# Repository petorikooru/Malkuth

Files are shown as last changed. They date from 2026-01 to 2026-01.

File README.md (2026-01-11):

# Malkuth

Idk, the name just comes up in my head (that malkuth from BA)

> [!CAUTION]
> For now, DO NOT USE the PCB Design unless you know what you are doing.
> There are quite silly (and tiny bit major) design flaws on there

> [!NOTE]  
> For now, the audio handling is a bit stuttery on some FLAC audio
> (especially on 24 bit one). I will make it a todo list for now

Basically it is a rewrite version of the previous project of mine [uta](https://github.com/petorikooru/uta)

I create this to fulfill my final project of Microcomputer class lmao.

## Dependencies

- TFT_eSPI + FT6236 + PNGdec
- arduino-audio-tools + libfoxenflac + libmp3helix + libaac + libwav
- SdFat

## Hardware Components

- ILI9488 Capacitive Touch Screen Display
- PCM5102a DAC
- MicroSD Card Module
- ESP32-S3 N16R8
- Kailh Choc v2 switch
- Other small components stuff

For now, 16 MB Storage size is needed to keep the font files (they take like 50% of the spaces 💀). I will make them .vlw files and store it inside SPIFFS or LittleFS (that is the task of future me though)

## Screenshot

<table>
  <tr>
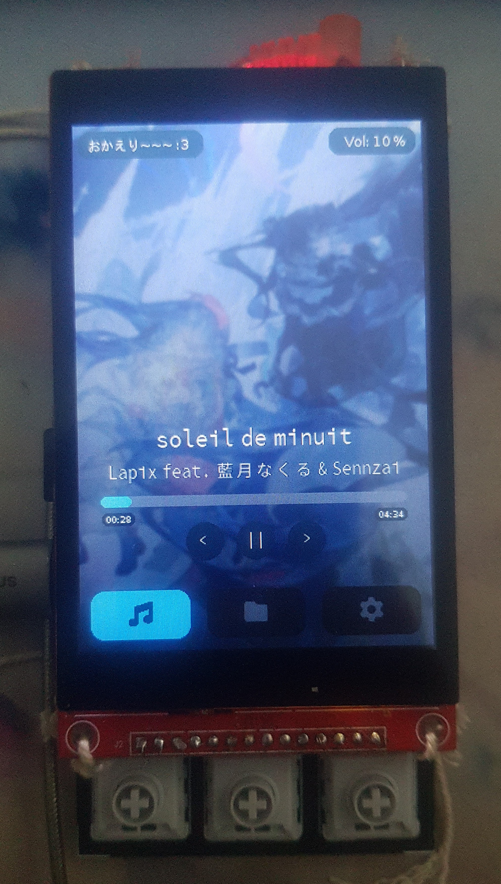
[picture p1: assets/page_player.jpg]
Player Menu
    <td> </td>
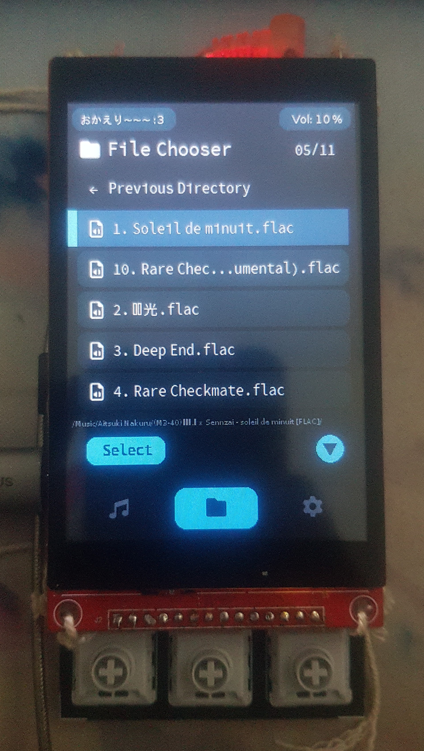
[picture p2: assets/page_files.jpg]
Files Menu
    <td> </td>
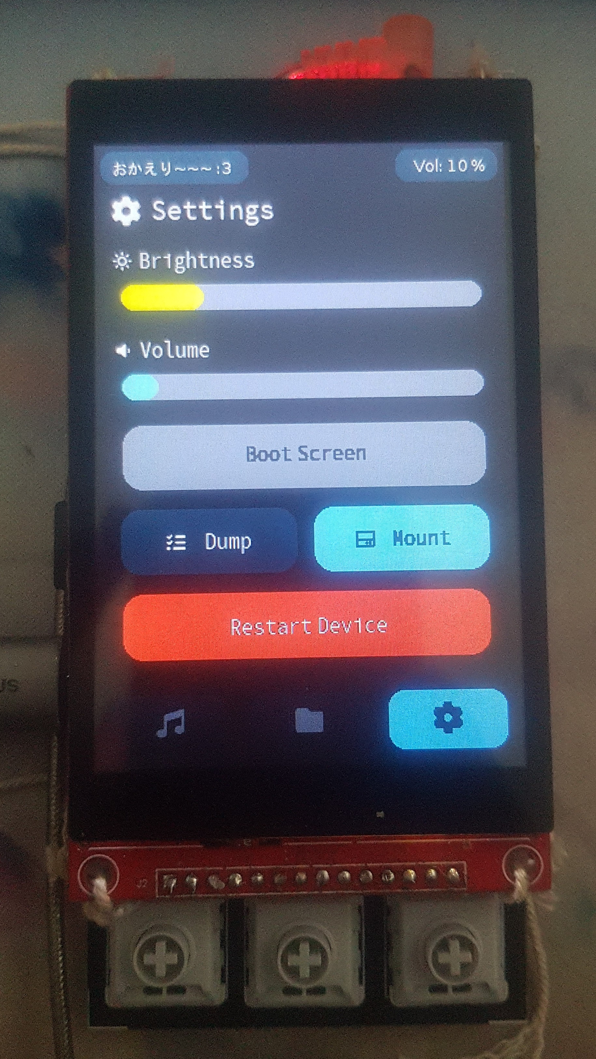
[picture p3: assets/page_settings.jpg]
Settings Menu
    <td> </td>
  </tr> 
</table>

## TODO List

- Make the audio a task itself just like Display (The main trouble is that SdFat is not really thread safe)
- Actually handle audio cover image (jpg and png)
- More performance fixing stuff
- ~Actually handle UI correctly instead of reloading from scratch~ (Kinda done?)
- 3D Printable Case

## Far (not really) to the future TODO LIST

- Maybe split the processing to different chip so that the Display will be driven by RP2040 and the Audio (and perhaps even bluetooth functionality) will be driven by ESP32-S3 (or more powerful counterpart)
- Fix the PCB Design and implement actual charging functionality
- Add speaker (maybe will salvage from iphone speaker or something) and implement automatic audio switching
- RTC clock?
- Animation (i dont think it is powerful enough though)

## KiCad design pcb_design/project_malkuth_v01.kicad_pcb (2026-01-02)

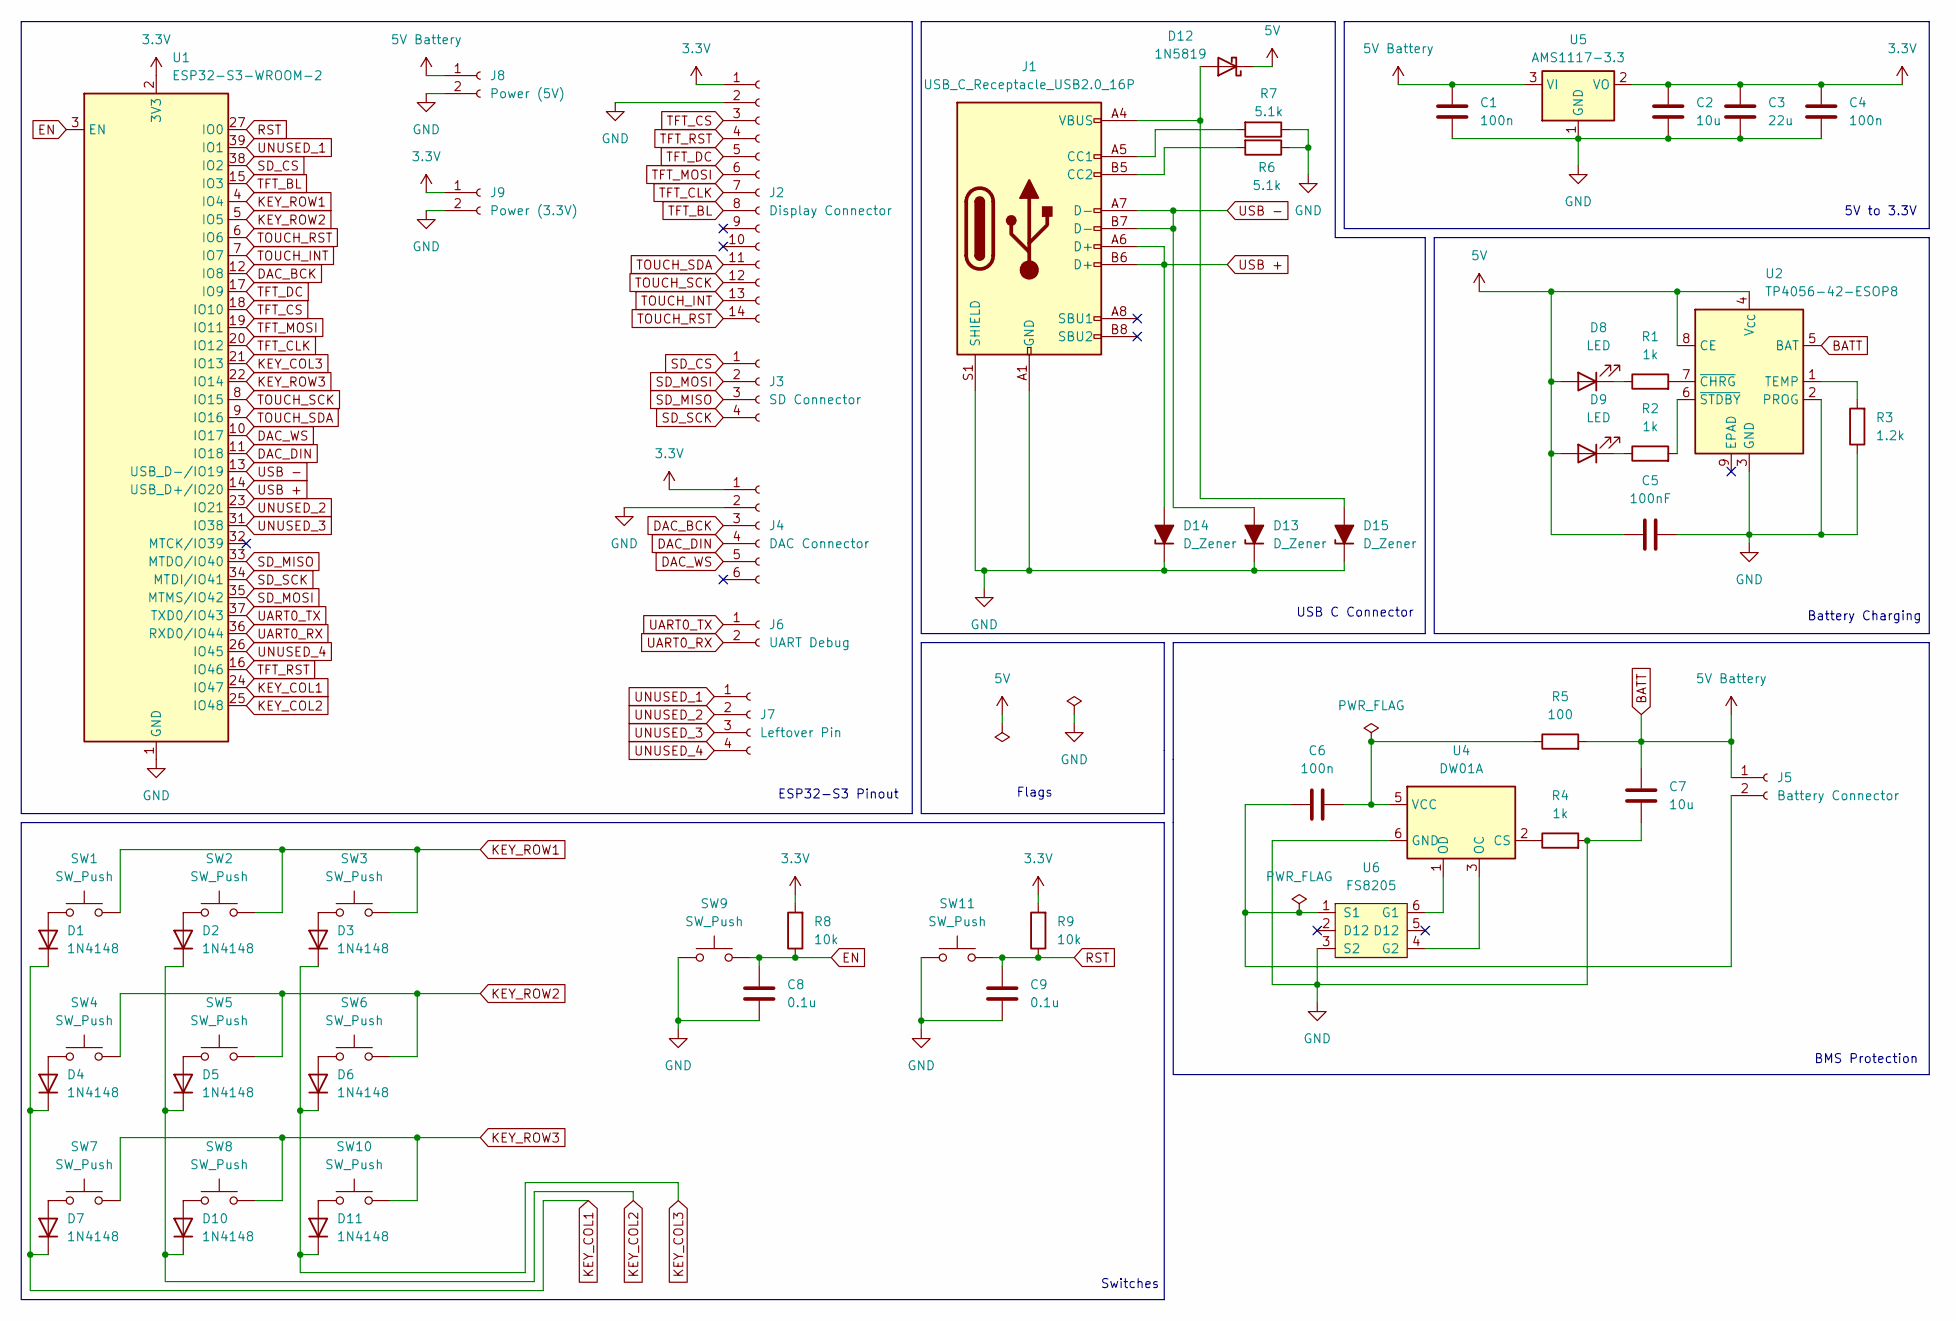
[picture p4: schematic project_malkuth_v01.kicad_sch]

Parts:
C1, C4, C6: 100n; C_0805_2012Metric
C2, C7: 10u; C_0805_2012Metric
C3: 22u; C_0805_2012Metric
C5: 100nF
C8, C9: 0.1u
D1, D2, D3, D4, D5, D6, D7, D10, D11: 1N4148; D_DO-35_SOD27_P7.62mm_Horizontal
D8, D9: LED; LED_0805_2012Metric
D12: 1N5819; D_DO-41_SOD81_P10.16mm_Horizontal
D13, D14, D15: D_Zener; Littelfuse_PolyZen-LS
J1: USB_C_Receptacle_USB2.0_16P; USB_C_Receptacle_GCT_USB4105-xx-A_16P_TopMnt_Horizontal
J2: Display Connector; PinSocket_1x14_P2.00mm_Vertical
J3: SD Connector; PinSocket_1x04_P2.00mm_Vertical
J4: DAC Connector; PinHeader_1x06_P2.00mm_Vertical
J5: Battery Connector; PinSocket_1x02_P2.54mm_Vertical
J6: UART Debug; PinSocket_1x02_P2.00mm_Vertical
J7: Leftover Pin; PinSocket_1x04_P2.00mm_Vertical
J8: Power (5V); PinSocket_1x02_P2.00mm_Vertical
J9: Power (3.3V); PinSocket_1x02_P2.00mm_Vertical
R1, R2, R4: 1k; R_0805_2012Metric
R3: 1.2k; R_0805_2012Metric
R5: 100; R_0805_2012Metric
R6, R7: 5.1k; R_0805_2012Metric
R8, R9: 10k; R_0805_2012Metric
SW1, SW2, SW3: SW_Push; SW_Hotswap_Kailh_Choc_V1V2
SW4, SW5, SW6, SW7, SW8, SW10: SW_Push; SW_Tactile_SPST_Angled_PTS645Vx39-2LFS
SW9, SW11: SW_Push; SW_PUSH_6mm
U1: ESP32-S3-WROOM-2
U2: TP4056-42-ESOP8; SOIC-8-1EP_3.9x4.9mm_P1.27mm_EP2.41x3.3mm_ThermalVias
U4: DW01A; SOT-23-6
U5: AMS1117-3.3; SOT-223-3_TabPin2
U6: FS8205; SOT-23-6; LCSC C32254

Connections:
3.3V: C2.1, C3.1, C4.1, J2.1, J4.1, J9.1, R8.2, R9.2, U1.2 (3V3), U5.2 (VO)
5V: C5.2, D8.2 (A), D9.2 (A), D12.1 (K), U2.4 (V_{CC}), U2.8 (CE)
BATT: C1.1, C7.1, J5.1, J8.1, R5.2, U2.5 (BAT), U5.3 (VI)
DAC_BCK: J4.3, U1.12 (IO8)
DAC_DIN: J4.4, U1.11 (IO18)
DAC_WS: J4.5, U1.10 (IO17)
EN: C8.1, R8.1, SW9.2, U1.3 (EN)
GND: C1.2, C2.2, C3.2, C4.2, C5.1, C7.2, C8.2, C9.2, D13.1 (K), D14.1 (K), D15.1 (K), J1.A1 (GND), J1.A12 (GND), J1.B1 (GND), J1.B12 (GND), J1.S1 (SHIELD), J2.2, J4.2, J8.2, J9.2, R3.1, R4.2, R6.1, R7.1, SW9.1, SW11.1, U1.1 (GND), U1.40 (GND), U1.41 (GND), U2.2 (PROG), U2.3 (GND), U4.6 (GND), U5.1 (GND), U6.3 (S2)
KEY_COL1: D1.1 (K), D4.1 (K), D7.1 (K), U1.24 (IO47)
KEY_COL2: D2.1 (K), D5.1 (K), D10.1 (K), U1.25 (IO48)
KEY_COL3: D3.1 (K), D6.1 (K), D11.1 (K), U1.21 (IO13)
KEY_ROW1: SW1.2, SW2.2, SW3.2, U1.4 (IO4)
KEY_ROW2: SW4.2, SW5.2, SW6.2, U1.5 (IO5)
KEY_ROW3: SW7.2, SW8.2, SW10.2, U1.22 (IO14)
unnamed: D1.2 (A), SW1.1
unnamed: D2.2 (A), SW2.1
unnamed: D3.2 (A), SW3.1
unnamed: D4.2 (A), SW4.1
unnamed: D5.2 (A), SW5.1
unnamed: D6.2 (A), SW6.1
unnamed: D7.2 (A), SW7.1
unnamed: D8.1 (K), R1.1
unnamed: D9.1 (K), R2.1
unnamed: D10.2 (A), SW8.1
unnamed: D11.2 (A), SW10.1
unnamed: D12.2 (A), D15.2 (A), J1.A4 (VBUS), J1.A9 (VBUS), J1.B4 (VBUS), J1.B9 (VBUS)
unnamed: J1.A5 (CC1), R7.2
unnamed: J1.B5 (CC2), R6.2
unnamed: C6.1, J5.2, U6.1 (S1)
unnamed: R3.2, U2.1 (TEMP)
unnamed: R1.2, U2.7 (~CHRG)
unnamed: R2.2, U2.6 (~STDBY)
unnamed: R4.1, U4.2 (CS)
unnamed: U4.3 (OC), U6.4 (G2)
unnamed: U4.1 (OD), U6.6 (G1)
unnamed: C6.2, R5.1, U4.5 (VCC)
RST: C9.1, R9.1, SW11.2, U1.27 (IO0)
SD_CS: J3.1, U1.38 (IO2)
SD_MISO: J3.3, U1.33 (MTDO/IO40)
SD_MOSI: J3.2, U1.35 (MTMS/IO42)
SD_SCK: J3.4, U1.34 (MTDI/IO41)
TFT_BL: J2.8, U1.15 (IO3)
TFT_CLK: J2.7, U1.20 (IO12)
TFT_CS: J2.3, U1.18 (IO10)
TFT_DC: J2.5, U1.17 (IO9)
TFT_MOSI: J2.6, U1.19 (IO11)
TFT_RST: J2.4, U1.16 (IO46)
TOUCH_INT: J2.13, U1.7 (IO7)
TOUCH_RST: J2.14, U1.6 (IO6)
TOUCH_SCK: J2.12, U1.8 (IO15)
TOUCH_SDA: J2.11, U1.9 (IO16)
UART0_RX: J6.2, U1.36 (RXD0/IO44)
UART0_TX: J6.1, U1.37 (TXD0/IO43)
UNUSED_1: J7.1, U1.39 (IO1)
UNUSED_2: J7.2, U1.23 (IO21)
UNUSED_3: J7.3, U1.31 (IO38)
UNUSED_4: J7.4, U1.26 (IO45)
USB +: D14.2 (A), J1.A6 (D+), J1.B6 (D+), U1.14 (USB_D+/IO20)
USB -: D13.2 (A), J1.A7 (D-), J1.B7 (D-), U1.13 (USB_D-/IO19)

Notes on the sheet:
5V to 3.3V
Flags
BMS Protection
Switches
ESP32-S3 Pinout
Battery Charging
USB C Connector

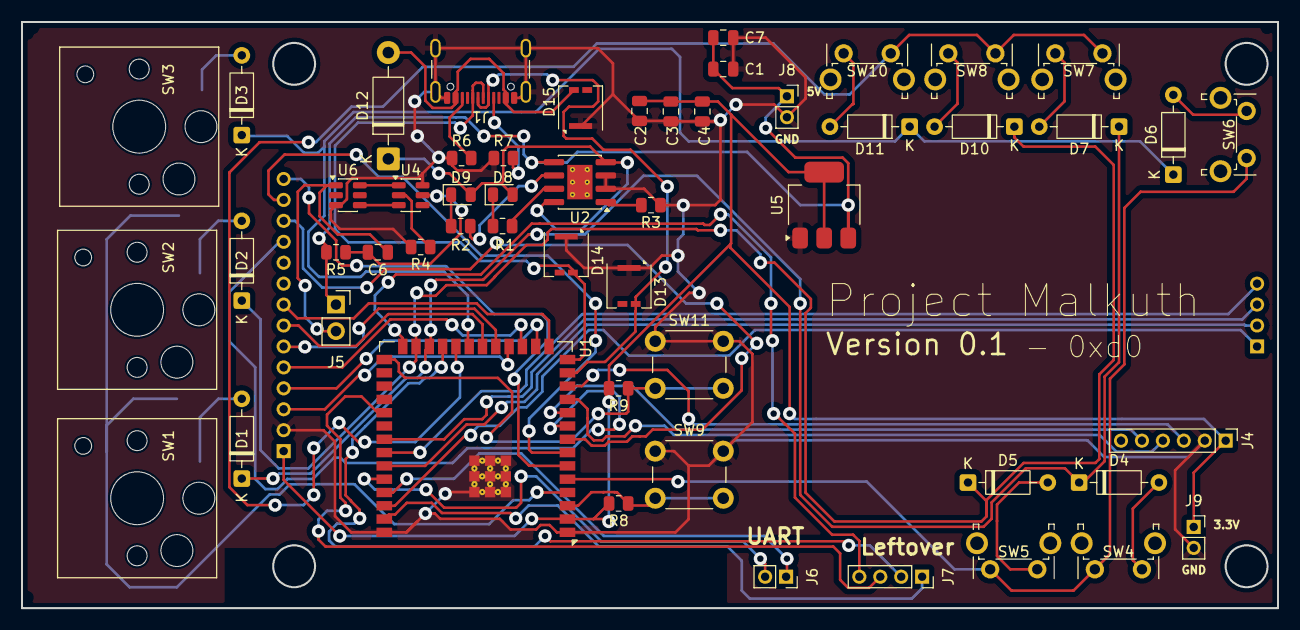
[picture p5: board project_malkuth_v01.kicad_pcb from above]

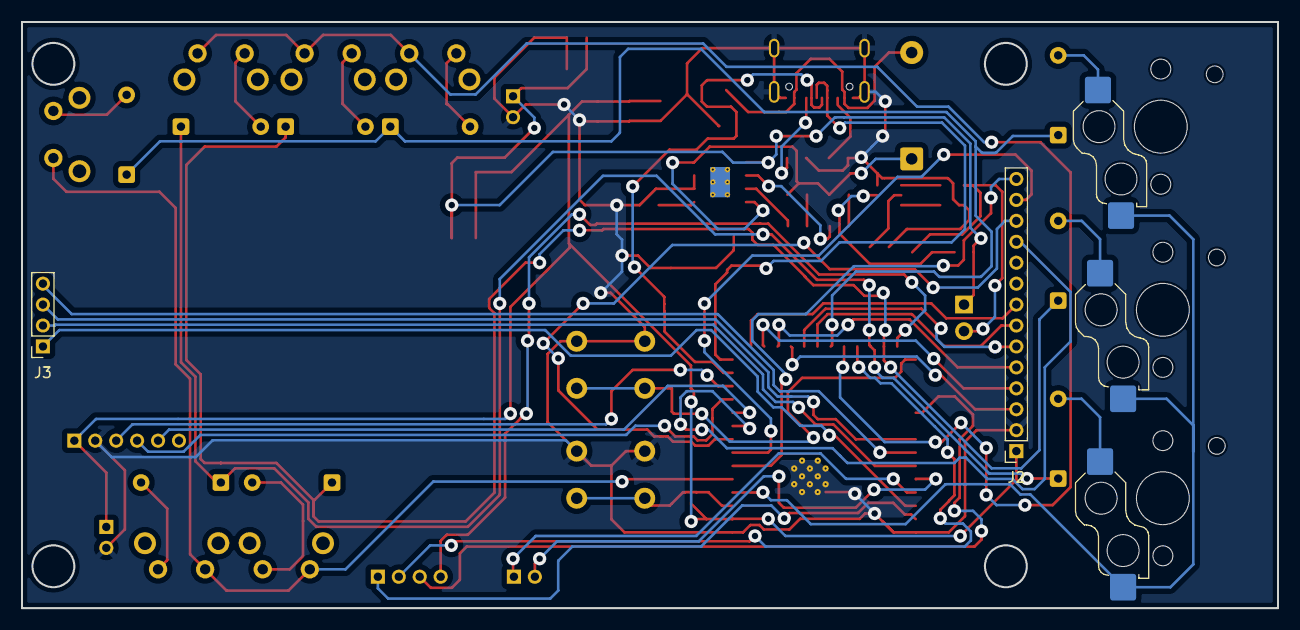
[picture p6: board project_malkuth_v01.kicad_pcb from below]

Board: 2 copper layers, 120.0 x 56.0 mm, 55 parts (2 on the bottom side), 59 nets.

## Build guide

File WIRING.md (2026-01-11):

# Wiring

Here's the wiring for the components

> [!IMPORTANT]
> For the display, you must change it inside the "User_Setup.h" on TFT_eSPI library

## PCM5102a DAC

- BCK       : 8
- WS/LCK    : 17
- DATA/DIN  : 18

## ILI9488 Display

### Display

- DC    : 9
- CS    : 10
- MOSI  : 11
- CLK   : 12
- BL    : 3
- RST   : 46

### Touch

- RST   : 6
- INT   : 7
- SCK   : 15
- SDA   : 16

## SD Card

- CS    : 2
- MISO  : 40
- SCK   : 41
- MOSI  : 42

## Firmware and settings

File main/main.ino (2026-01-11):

#include <Arduino.h>
#include <vector>
#include <Keypad.h>

#include "malkuth_fs.h"

#include "malkuth_display.h"
#include "malkuth_audio.h"

#include "fonts/Koruri-Regular12.h"
#include "fonts/Koruri-Regular8.h"
#include "fonts/RelaxedTypingMonoJP-Regular.ttf18.h"
#include "fonts/RelaxedTypingMonoJP-Regular.ttf24.h"

#include "fonts/Icons.h"
#include "fonts/IconsMenubar.h"

#include "flash_images/BootBg.h"
#include "flash_images/PlayerBg_a.h"
#include "flash_images/PlayerBg_b.h"
#include "flash_images/PlayerBg_c.h"
#include "flash_images/PlayerBg_d.h"

////////////////////////////////////////////////////////////////////
//                             Theming                            //
////////////////////////////////////////////////////////////////////
namespace Theme {
    constexpr uint16_t C_BG             = TFT_BLACK;
    constexpr uint16_t C_CARD           = TFT_DARKGREY;

    constexpr uint16_t C_ACCENT         = 0x5e1a;
    constexpr uint16_t C_ACCENT_DARK    = 0x11a7;
    constexpr uint16_t C_ACCENT_MUTED   = 0x1a09;
    constexpr uint16_t C_ACCENT_EXMUTED = 0x0904;

    constexpr uint16_t C_TEXT_PRIMARY   = TFT_WHITE;
    constexpr uint16_t C_TEXT_MUTED     = 0x7BEF;
    
    constexpr uint16_t C_SUCCESS        = TFT_GREEN;
    constexpr uint16_t C_WARNING        = TFT_YELLOW;
    constexpr uint16_t C_ERROR          = TFT_RED;

    constexpr uint16_t C_WHITE          = TFT_WHITE;
    constexpr uint16_t C_BLACK          = TFT_BLACK;

    constexpr uint8_t  R_SMALL  = 8;
    constexpr uint8_t  R_MEDIUM = 12;
    constexpr uint8_t  R_LARGE  = 16;

    const uint8_t*  FONT_SMALL      = Koruri_Regular8;
    const uint8_t*  FONT_MEDIUM     = Koruri_Regular12;
    const uint8_t*  FONT_LARGE      = RelaxedTypingMonoJP_Regular18;
    const uint8_t*  FONT_HUGE       = RelaxedTypingMonoJP_Regular24;

    const uint8_t*  FONT_ICON_LARGE       = IconsMenubar;
    const uint8_t*  FONT_ICON_SMALL       = Icons;

    const uint8_t*      IMG_BOOT        = BootBg;
    const uint8_t*      IMG_PLAYER      = PlayerBg_b;
    constexpr size_t    IMG_BOOT_SIZE   = sizeof(BootBg);
    constexpr size_t    IMG_PLAYER_SIZE = sizeof(PlayerBg_b);

}
////////////////////////////////////////////////////////////////////
//                        Global Variables                        //
////////////////////////////////////////////////////////////////////
MalkuthDisplay  display;
MalkuthFs       filesystem;
MalkuthAudio    audio;

AudioMetadata   metadata;

enum class Page : uint8_t {
    NONE,
    BOOT_SCREEN,
    PLAYER,
    FILES,
    SETTINGS,
};

Page    current_page = Page::NONE;
uint8_t current_volume      = 10;
uint8_t current_brightness  = 50;

char vol_buf[16]     = {};
char time_buf[12]    = {};
char notif_buf[64]   = {};
char idx_buf[12]     = {};    

// Player
float       position = 0.0f;
float       duration = 0.0f;
uint8_t     progress = 0;

// Files
char current_directory[128]  = "/";
char selected_directory[128] = "";
String  current_audiopath    = "";

std::vector<String> files;
uint16_t            previous_index      = 0;
uint16_t            files_count         = 0;
constexpr uint8_t   VISIBLE_ITEMS       = 5;
constexpr size_t    MAX_VISIBLE_STRING  = 29;
uint16_t            start_idx           = 0;
uint16_t            end_idx             = 0;

// Settings
constexpr uint16_t SLIDER_WIDTH = 280;
constexpr uint16_t SLIDER_HEIGHT = 20;

TimerHandle_t timer_notif = NULL;
TimerHandle_t timer_player = NULL;

////////////////////////////////////////////////////////////////////
//                        Function Prototype                      //
////////////////////////////////////////////////////////////////////
void page(Page p, bool redraw = false);
void page_boot();
void page_settings();
void page_player();
void page_files();
void page_files_listing(uint8_t index);

void show_statusbar();
void show_menubar(Page active);
void show_notification(const char* text, uint16_t color, uint16_t delay_ms);

void check_keypress();
void check_progress();
void check_metadata();

void start_player_timer();
void stop_player_timer();

void format_duration(char* out, size_t len, float seconds);
String format_elipsis(const String& text, uint8_t length);

bool is_audio_file(const String& f);
bool is_image_file(const String& f);
bool is_directory(const String& f);

////////////////////////////////////////////////////////////////////
//                         Actual Program                         //
////////////////////////////////////////////////////////////////////
void setup() {
    Serial.begin(115200);

    display.init(0);
    page(Page::BOOT_SCREEN);

    delay(1); // A bit weird fix because somehow the SD Card failed to be initialized if i dont add delay first

    if (!filesystem.init())
        display.text(Anchor::BOTTOM_CENTER, false, "SD Card is failed to be mounted!", Theme::FONT_SMALL, Theme::C_ERROR, 0, -10);
    else
        display.text(Anchor::BOTTOM_CENTER, false, "SD Card is successfully mounted!", Theme::FONT_SMALL, Theme::C_SUCCESS, 0, -10);

    audio.set_sdfs(filesystem.get_sdfs());
    // display.set_sdfs(filesystem.get_sdfs());

    if (!audio.init())
        display.text(Anchor::BOTTOM_CENTER, false, "Audio is failed to be intialized!", Theme::FONT_SMALL, Theme::C_ERROR, 0, -30);
    else 
        display.text(Anchor::BOTTOM_CENTER, false, "Audio is successfully intialized!", Theme::FONT_SMALL, Theme::C_SUCCESS, 0, -30);

    // Initial value
    display.set_brightness(current_brightness);
    audio.set_volume(current_volume);
}

void loop() {
    audio.loop();

    check_metadata();
    check_keypress();
    display.check_buttons();
}

////////////////////////////////////////////////////////////////////
//                          Page Element                          //
////////////////////////////////////////////////////////////////////
void page(Page p, bool redraw) {
    if (current_page == p && !redraw) return;

    if (current_page == Page::PLAYER) stop_player_timer();

    current_page = p;

    if (current_page == Page::PLAYER) start_player_timer();

    display.buttons_clear();
    display.clear();

    if (current_page != Page::BOOT_SCREEN && current_page != Page::PLAYER) {
        show_statusbar();
        show_menubar(current_page);
    }

    switch (p) {
        case Page::BOOT_SCREEN: page_boot(); break;
        case Page::PLAYER:      page_player(); break;
        case Page::FILES:       page_files(); break;
        case Page::SETTINGS:    page_settings(); break;
        default: break;
    }
}

////////////////////////////////////////////////////////////////////
//                           Page Boot                            //
////////////////////////////////////////////////////////////////////
void page_boot() {
    display.image(ImageType::FLASH, Theme::IMG_BOOT, Theme::IMG_BOOT_SIZE);
    display.text(Anchor::TOP_CENTER,    true, "おかえり~~~ :3",       Theme::FONT_HUGE,  Theme::C_BG, 0, 20);
    display.text(Anchor::BOTTOM_CENTER, true, " > Touch to start <", Theme::FONT_HUGE, Theme::C_TEXT_PRIMARY, 0, -60);
 
    display.button(Anchor::MIDDLE_CENTER, 320, 480, 0, 0, [](void*) {
        page(Page::PLAYER);
    });
}

////////////////////////////////////////////////////////////////////
//                           Page Player                          //
////////////////////////////////////////////////////////////////////
void page_player() {
    // TODO : Maybe i will fix later (Cover image loading)
    //
    // if (audio.get_covertype() == ImageType::NONE)
    //     display.object(Anchor::MIDDLE_CENTER, 200, 200, Theme::C_CARD, 10, 0, -80);
    //     display.image(ImageType::FLASH, PlayerBg, sizeof(BootBg));
    // else
    //     display.image(audio.get_covertype(), audio.get_coverpath(), 200, 200, 60, 40);

    display.image(ImageType::FLASH, Theme::IMG_PLAYER, Theme::IMG_PLAYER_SIZE);

    show_statusbar();
    show_menubar(current_page);

    // Artist and title text
    display.text(Anchor::MIDDLE_CENTER, true, metadata.title.c_str(), Theme::FONT_HUGE, Theme::C_TEXT_PRIMARY, 0, 50);
    display.text(Anchor::MIDDLE_CENTER, true, metadata.artist.c_str(), Theme::FONT_LARGE, Theme::C_TEXT_PRIMARY, 0, 80);

    // Duration text
    format_duration(time_buf, sizeof(time_buf), metadata.duration);
    display.object(Anchor::BOTTOM_RIGHT, 30, 12, Theme::C_ACCENT_DARK, 5, -20, -113);
    display.text(Anchor::BOTTOM_RIGHT, true, time_buf, Theme::FONT_SMALL, Theme::C_WHITE, -20, -110);

    // Button for Play/Pause
    display.button(Anchor::BOTTOM_CENTER, 35, 35, Theme::C_ACCENT_MUTED, -1, 0, -80, [](void*){
        audio.toggle();        
        display.object(Anchor::BOTTOM_CENTER, 35, 35, Theme::C_ACCENT_MUTED, -1, 0, -80);
        display.text(Anchor::BOTTOM_CENTER, true, 
            audio.get_status() ? "||" : "▶", 
            Theme::FONT_LARGE, Theme::C_WHITE, 
            audio.get_status() ? -1 : 2, 
            audio.get_status() ? -85 : -82
        );
    });
    display.text(Anchor::BOTTOM_CENTER, true, 
            audio.get_status() ? "||" : "▶", 
            Theme::FONT_LARGE, Theme::C_WHITE, 
            audio.get_status() ? -1 : 2, 
            audio.get_status() ? -85 : -82
    );

    // Button for < (Previous)
    display.button(Anchor::BOTTOM_CENTER, 35, 35, Theme::C_ACCENT_MUTED, -1, -46, -80, [](void*){
        audio.previous();
        show_notification("Previous Track", Theme::C_ACCENT, 500);
    });
    display.text(Anchor::BOTTOM_CENTER, true, "<", Theme::FONT_LARGE, Theme::C_WHITE, -48, -85);

    // Button for > (Next)
    display.button(Anchor::BOTTOM_CENTER, 35, 35, Theme::C_ACCENT_MUTED, -1, 47, -80, [](void*){
        audio.next();
        show_notification("Next Track", Theme::C_ACCENT, 500);
    });
    display.text(Anchor::BOTTOM_CENTER, true, ">", Theme::FONT_LARGE, Theme::C_WHITE, 47, -85);

    if (metadata.duration <= 0) {
        display.text(Anchor::BOTTOM_CENTER, true, "Select a Directory to Play!", Theme::FONT_LARGE, Theme::C_TEXT_PRIMARY, 0, -150);
    }
}

void check_metadata(){
    if (audio.get_update()) {
        metadata = audio.get_metadata();
        audio.yeah_i_have_updated();

        current_audiopath = String(audio.get_audiopath());

        if (!audio.is_actually_audio()) {
            return;
        }

        if (current_page == Page::PLAYER) {
            display.image(ImageType::FLASH, Theme::IMG_PLAYER, Theme::IMG_PLAYER_SIZE, 320, 85, 0, 280);
            display.text(Anchor::MIDDLE_CENTER, true, metadata.title.c_str(), Theme::FONT_HUGE, Theme::C_TEXT_PRIMARY, 0, 50);
            display.text(Anchor::MIDDLE_CENTER, true, metadata.artist.c_str(), Theme::FONT_LARGE, Theme::C_TEXT_PRIMARY, 0, 80);

            // Duration text
            format_duration(time_buf, sizeof(time_buf), metadata.duration);
            display.object(Anchor::BOTTOM_RIGHT, 30, 12, Theme::C_ACCENT_DARK, 5, -20, -113);
            display.text(Anchor::BOTTOM_RIGHT, true, time_buf, Theme::FONT_SMALL, Theme::C_WHITE, -20, -110);
        }

        if (current_page == Page::FILES && (strcmp(current_directory, selected_directory) == 0))
            page_files_listing(start_idx);
    }
}
////////////////////////////////////////////////////////////////////
//                      Progress Bar Update                       //
////////////////////////////////////////////////////////////////////
static void player_update_timer(TimerHandle_t xTimer) {
    check_progress();
}

void start_player_timer() {
    if (!timer_player) {
        timer_player = xTimerCreate(
            "Malkuth: Progress timer",
            pdMS_TO_TICKS(1000),
            pdTRUE,
            nullptr,
            player_update_timer
        );
    }

    xTimerStop(timer_player, 0);
    xTimerStart(timer_player, 0);
}

void stop_player_timer() {
    if (timer_player) {
        xTimerStop(timer_player, 0);
    }
}

void check_progress(){
    // The progress bar
    if (current_page != Page::PLAYER)
        return;

    if (!audio.get_status())
        return;

    duration = metadata.duration;
    if (duration <= 0)
        return;

    position = audio.get_position();
    progress = constrain(static_cast<uint8_t>((position / duration) * 100), 0, 100);
        
    // Player UI Update
    format_duration(time_buf, sizeof(time_buf), position);
    display.bar(Anchor::BOTTOM_CENTER, 280, 10, Theme::C_CARD, Theme::C_ACCENT, 5, 0, -130, progress, [](void*){
        TouchData p = display.get_touchdata();
        if (p.z == 0) return;
        
        uint8_t val = map(constrain(p.x, 5, 285), 5, 285, 0, 100);

        progress = val;
        Serial.println(progress);
        audio.set_position(progress);
        display.bar(Anchor::BOTTOM_CENTER, 280, 10, Theme::C_CARD, Theme::C_ACCENT, 5, 0, -130, progress, nullptr);
    });
    display.object(Anchor::BOTTOM_LEFT, 30, 12, Theme::C_ACCENT_DARK, 5, 21, -113);
    display.text(Anchor::BOTTOM_LEFT, true, time_buf, Theme::FONT_SMALL, Theme::C_WHITE, 20, -110);
}

////////////////////////////////////////////////////////////////////
//                           Page Files                          //
////////////////////////////////////////////////////////////////////
void page_files() {
    display.text(Anchor::TOP_LEFT, true, "", Theme::FONT_ICON_LARGE, Theme::C_WHITE, 10, 35);     // Folder Icon
    display.text(Anchor::TOP_LEFT, true, "File Chooser", Theme::FONT_HUGE, Theme::C_WHITE, 40, 38);

    // Previous dir button
    display.button(Anchor::TOP_CENTER, 300, 40, Theme::C_BG, 10, 0, 75, [start_idx](void*) {
        size_t len = strlen(current_directory);
        if (len > 1) {
            for (int i = len - 2; i >= 0; --i) {
                if (current_directory[i] == '/') {
                    current_directory[i + 1] = '\0';
                    break;
                }
            }
            page_files_listing(previous_index);
        }
    });
    display.text(Anchor::TOP_LEFT, true, "←   Previous Directory", Theme::FONT_LARGE, Theme::C_TEXT_PRIMARY, 20, 84);

    // Directory Listing
    page_files_listing(0);
}

void page_files_listing(uint8_t index) {
    display.buttons_clear_temp();

    // Refresh the view 
    display.object(Anchor::TOP_CENTER, 320, 240, TFT_BLACK, 0, 0, 120);
    display.object(Anchor::BOTTOM_RIGHT, 30, 30, Theme::C_BLACK, -1, -60, -80);
    display.object(Anchor::BOTTOM_RIGHT, 30, 30, Theme::C_BLACK, -1, -20, -80);
    
    files       = filesystem.get_directory_files(current_directory);
    files_count = files.size();

    start_idx   = index;
    end_idx     = start_idx + VISIBLE_ITEMS;

    if (end_idx > files_count) 
        end_idx = files_count;

    // List files and directory
    snprintf(idx_buf, sizeof(idx_buf), "%02u/%02u", end_idx, files_count);
    display.object(Anchor::TOP_RIGHT, 50, 30, Theme::C_BLACK, 0, -20, 38);
    display.text(Anchor::TOP_RIGHT, true, idx_buf, Theme::FONT_LARGE, Theme::C_WHITE, -20, 42);
    
    for (uint8_t i = 0; i < VISIBLE_ITEMS; ++i) {
        uint8_t idx = start_idx + i;
        if (idx >= files_count) break;

        int16_t y_offset = 75 + ((i + 1) * 45);
        const String& file = files[idx];

        String displayed_text = format_elipsis(file, MAX_VISIBLE_STRING);

        bool currently_played = (current_audiopath == (String(current_directory) + file)) && (current_audiopath != "");

        display.button( 
            Anchor::TOP_CENTER, 300, 40, 
            currently_played ? Theme::C_ACCENT_MUTED: Theme::C_ACCENT_EXMUTED, 
            currently_played ? 0 : 10, 
            0, y_offset, 
        [file, start_idx, idx](void*) {
            if (is_directory(file)) {
                strncat(current_directory, file.c_str(), sizeof(current_directory) - strlen(current_directory) - 1);
                previous_index = start_idx;
                page_files_listing(0);
            } else if (is_audio_file(file)){
                // if (strcmp(selected_directory, current_directory) == 0)
                //     audio.set_index(idx);
                // else
                //     show_notification("You haven't selected this dir!", Theme::C_ACCENT, 1000);

                if (strcmp(selected_directory, current_directory) == 0)
                    audio.set_index(idx);
                else {
                    strcpy(selected_directory, current_directory);
                    audio.process_directory(selected_directory);

                    audio.set_index(idx);
                }
            }
        }, nullptr, true);

        if (currently_played){
            display.object(Anchor::TOP_LEFT, 10, 40, Theme::C_ACCENT, 0, 0, y_offset);
        }

        if (is_audio_file(file))
            display.text(Anchor::TOP_LEFT, true, "", Theme::FONT_ICON_SMALL, Theme::C_TEXT_PRIMARY, 20, 82 + (i + 1) * 45); // Audio Icon
        else if (is_image_file(file))
            display.text(Anchor::TOP_LEFT, true, "", Theme::FONT_ICON_SMALL, Theme::C_TEXT_PRIMARY, 20, 82 + (i + 1) * 45); // Image Icon
        else if (is_directory(file))
            display.text(Anchor::TOP_LEFT, true, "", Theme::FONT_ICON_SMALL, Theme::C_TEXT_PRIMARY, 20, 82 + (i + 1) * 45); // Folder Icon
        else
            display.text(Anchor::TOP_LEFT, true, "", Theme::FONT_ICON_SMALL, Theme::C_TEXT_PRIMARY, 20, 82 + (i + 1) * 45); // File Icon

        display.text(Anchor::TOP_LEFT, true, displayed_text.c_str(), Theme::FONT_LARGE, Theme::C_TEXT_PRIMARY, 45, 84 + (i + 1) * 45);
    }

    display.text(Anchor::BOTTOM_LEFT, true, format_elipsis(String(current_directory), 78).c_str(), Theme::FONT_SMALL, Theme::C_TEXT_MUTED, 0, -116);

    // Select the directory
    bool selected = (strcmp(selected_directory, current_directory) == 0);
    display.button(Anchor::BOTTOM_LEFT, 85, 30, selected ? Theme::C_ACCENT : Theme::C_ACCENT_DARK, 10, 20, -80, [](void*) {
        strcpy(selected_directory, current_directory);
        audio.process_directory(selected_directory);
    }, nullptr, true);
    display.text(Anchor::BOTTOM_LEFT, true, "Select", Theme::FONT_LARGE, selected ? Theme::C_BG : Theme::C_TEXT_PRIMARY, 33, -81);

    // Return to the selected directory
    display.object(Anchor::BOTTOM_CENTER, 85, 30, Theme::C_BLACK, 0, 0, -80);
    if ((!(strcmp(selected_directory, "") == 0)) && (!(strcmp(selected_directory, current_directory) == 0))) {
        display.button(Anchor::BOTTOM_CENTER, 85, 30, Theme::C_ACCENT_DARK, 10, 0, -80, [](void*) {
            strcpy(current_directory, selected_directory);
            page_files_listing(0);
        }, nullptr, true);
        display.text(Anchor::BOTTOM_CENTER, true, "Now", Theme::FONT_LARGE, Theme::C_TEXT_PRIMARY, 0, -81);
    }

    // Scroll up
    if (start_idx > 0) {
        display.button(Anchor::BOTTOM_RIGHT, true, 30, 30, Theme::C_ACCENT, -1, -60, -80, [start_idx](void*) {
            page_files_listing(start_idx - 1);
        }, nullptr, true);
        display.text(Anchor::BOTTOM_RIGHT, true, "▲", Theme::FONT_LARGE, Theme::C_BLACK, -63, -80);
    }

    // Scroll down
    if (end_idx < files_count) {
        display.button(Anchor::BOTTOM_RIGHT, true, 30, 30, Theme::C_ACCENT, -1, -20, -80, [start_idx](void*) {
            page_files_listing(start_idx + 1);
        }, nullptr, true);
        display.text(Anchor::BOTTOM_RIGHT, true, "▼", Theme::FONT_LARGE, Theme::C_BLACK, -23, -80);
    }
}
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

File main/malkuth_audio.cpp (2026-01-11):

#include "malkuth_audio.h"

MalkuthAudio* MalkuthAudio::self = nullptr;

bool MalkuthAudio::init(uint8_t pin_bck, uint8_t pin_ws, uint8_t pin_data){
    AudioLogger::instance().begin(Serial, AudioLogger::Warning);
  
    auto config = _i2s.defaultConfig(TX_MODE);
        
    self = this;

    _source     = new AudioSourceVector<FsFile>(&file_to_stream_cb);
    _player     = new AudioPlayer(*_source, _i2s, _decoder);

    config.pin_bck  = pin_bck;
    config.pin_ws   = pin_ws;
    config.pin_data = pin_data;
    config.buffer_size = 1024 * 16;
    config.buffer_count = 6;

    _player->setMetadataCallback(&metadata_print_cb);
    _player->getStreamCopy().copyN(5);
    _player->setBufferSize(1024 * 16);
    _player->setAutoNext(true);
    _player->setAutoFade(true);

    _decoder_flac.setMaxBlockSize(1024 * 16);
    _decoder_flac.setInBufferSize(1024 * 8);
    _decoder_flac.setOutBufferSize(1024 * 16);
    _decoder_flac.setMaxChannels(4);

    _decoder.addDecoder(_decoder_mp3,   "audio/mpeg");
    _decoder.addDecoder(_decoder_wav,   "audio/vnd.wave");
    _decoder.addDecoder(_decoder_flac,  "audio/flac");

    if (!_i2s.begin(config)) {
      Serial.println("I2S failed to start");
      return false;
    }
    return true;
}

void MalkuthAudio::metadata_print_cb(MetaDataType type, const char* str, int len){
    return self->metadata_print(type, str, len);
}

void MalkuthAudio::metadata_print(MetaDataType type, const char* str, int len){
    // Serial.print("==> ");
    // Serial.print(toStr(type));
    // Serial.print(": ");
    // Serial.println(str);
}

FsFile* MalkuthAudio::file_to_stream_cb(const char* path, FsFile& old_file){
    return self->file_to_stream(path, old_file);
}

FsFile* MalkuthAudio::file_to_stream(const char* path, FsFile& old_file){
    if (old_file.isOpen()) {
      old_file.close();
    }
    reset();

    String path_str = String(path);
    String filename = path_str.substring(path_str.lastIndexOf('/') + 1);
    filename.toLowerCase();

    const char* file_extension[] = { ".mp3", ".flac", ".wav" };
    bool is_supported = false;
    
    for (const char* ext : file_extension) {
      if (filename.endsWith(ext)) {
        is_supported = true;
        break;
      }
    }

    // Skipping non audio file (trick)
    if (!is_supported) {
        _audio_file.open("");
        _current_track.title  = "";
        _current_track.artist = "";
        _current_track.album  = "";
        _not_a_music = true;
        return &_audio_file;
    }

    FsFile meta_file;

    if (meta_file.open(path)) {
        _current_track = get_metadata(meta_file, path);
        meta_file.close();
    }

    if (_current_track.title.isEmpty())  
        // _current_track.title   = getFileStem(path);
        _current_track.title = "Unknown Title";

    if (_current_track.artist.isEmpty()) 
        _current_track.artist  = "Unknown Artist";
      
    if (_current_track.album.isEmpty())  
        _current_track.album   = "Unknown Album";

    if (!_audio_file.open(path)) {
        _audio_file.open("");
        _current_track.title  = "";
        _current_track.artist = "";
        _current_track.album  = "";
        _not_a_music = true;
      return &_audio_file;
    }

    strncpy(_current_audiopath, path, sizeof(_current_audiopath));
    _not_a_music = false;
    return &_audio_file;
}

AudioMetadata MalkuthAudio::get_metadata_flac_vorbis(FsFile& file, uint32_t size) { 
    AudioMetadata metadata;
    uint32_t vendor_len;
    if (file.read(&vendor_len, 4) != 4) return metadata;

    file.seek(file.position() + vendor_len);

    uint32_t comment_count;
    if (file.read(&comment_count, 4) != 4) return metadata;

    const size_t max_buffer_size = 256;
    for (uint32_t i = 0; i < comment_count; i++) {
      uint32_t len;
      if (file.read(&len, 4) != 4) break;

      size_t read_len = std::min(len, static_cast<uint32_t>(max_buffer_size));
      char buf[read_len + 1];
      if (file.read(buf, read_len) != read_len) break;
      buf[read_len] = '\0';

      String entry = String(buf);
      if      (entry.startsWith("TITLE=")) metadata.title = entry.substring(6);
      else if (entry.startsWith("title=")) metadata.title = entry.substring(6);

      if      (entry.startsWith("ARTIST=")) metadata.artist = entry.substring(7);
      else if (entry.startsWith("artist=")) metadata.artist = entry.substring(7);

      if      (entry.startsWith("ALBUM=")) metadata.album = entry.substring(6);
      else if (entry.startsWith("album=")) metadata.album = entry.substring(6);
    }

    return metadata;
}

AudioMetadata MalkuthAudio::get_metadata_flac(FsFile& file) {
    AudioMetadata metadata;

    float temp_duration = 0.0f;

    file.seek(0);
    char sig[4];
    if (file.read(sig, 4) != 4 || strncmp(sig, "fLaC", 4) != 0) {
      return metadata;
    }

    bool last_block = false;
    while (!last_block) {
      uint8_t header[4];
      if (file.read(header, 4) != 4) break;

      last_block = header[0] & 0x80;
      uint8_t block_type = header[0] & 0x7F;
      uint32_t block_size = (header[1] << 16) | (header[2] << 8) | header[3];

      if (block_type == 0) {
        uint8_t buf[34];

        if (file.read(buf, 34) != 34) return metadata;
        uint32_t sample_rate = ((uint32_t)buf[10] << 12) | (buf[11] << 4) | ((buf[12] >> 4) & 0x0F);
        uint8_t channels = ((buf[12] & 0x0E) >> 1) + 1;
        uint8_t bps = (((buf[12] & 0x01) << 4) | ((buf[13] >> 4) & 0x0F)) + 1;
        uint64_t total_samples = ((uint64_t)(buf[13] & 0x0F) << 32) | ((uint64_t)buf[14] << 24) | ((uint64_t)buf[15] << 16) | ((uint64_t)buf[16] << 8) | buf[17];

        temp_duration = (float)total_samples / sample_rate;
        
        metadata.total_samples = total_samples;
        metadata.sample_rate  = sample_rate;
      } else if (block_type == 4) {
        metadata = get_metadata_flac_vorbis(file, block_size);
        metadata.duration = temp_duration;
        return metadata;
      } else {
        file.seek(file.position() + block_size);
      }
    }

    metadata.data_offset = file.position();
    metadata.duration = temp_duration;
    return metadata;
}

AudioMetadata MalkuthAudio::get_metadata_mp3v1(FsFile& file) {
    AudioMetadata metadata;

    if (file.size() < 128) return metadata;

    file.seek(file.size() - 128);
    char tag[3];
    if (file.read(tag, 3) != 3 || strncmp(tag, "TAG", 3)) return metadata;

    char buf[125] = { 0 };
    file.read((uint8_t*)buf, 125);

    char title[31] = { 0 }, artist[31] = { 0 }, album[31] = { 0 };
    strncpy(title, buf + 3, 30);
    strncpy(artist, buf + 33, 30);
    strncpy(album, buf + 63, 30);

    if (title[0])   metadata.title = String(title);
    if (artist[0])  metadata.artist = String(artist);
    if (album[0])   metadata.album = String(album);

    metadata.duration = get_metadata_mp3_duration(file);
    
    return metadata;
}
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

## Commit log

2026-01-02 HUGE Update basically
    [project_malkuth_v01-B_Cu.gbr, project_malkuth_v01-B_Mask.gbr, project_malkuth_v01-B_Paste.gbr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]
2026-01-02 Cleaning up some files
    [project_malkuth_v01-B_Cu.gbr, project_malkuth_v01-B_Mask.gbr, project_malkuth_v01-B_Paste.gbr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]
2026-01-07 UI Rendering is now localised + Rework some delay functions so that they are now non-blocking
    [main.ino, malkuth_audio.cpp, malkuth_display.h]
2026-01-11 Quite an overhaul on "files" page + You can now press the audio file to actually play it instead of needing to press the "select" button now
